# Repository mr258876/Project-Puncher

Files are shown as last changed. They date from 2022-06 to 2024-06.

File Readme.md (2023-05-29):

# Project Puncher
### 赛博音乐盒计划第二部分
### Cyber Musicbox Project Part II

## 项目文件结构 / Project File Structure
    |   Project Puncher
    |
    +---Models
    |       3D模型文件
    |       3D models of puncher
    +---Project_HolePuncher
    |       ESP32下位机程序
    |       Program for puncher controller based on ESP32
    +---Schematic
    |       项目电路图及PCB文件
    |       Circuit schematic & PCB
    \---Utilities
            上位机程序
            Host program runs on your PC

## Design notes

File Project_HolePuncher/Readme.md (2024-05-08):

# Project Puncher - 控制器程序 / Controller Program

## 硬件需求 / Hardware requirements
| 物品 / Item | 数量 / Amount |
|---|---|
| ESP32-S3-N16R8 | 1 |
| TMC2209 Stepper Driver | 3 |
| P028B123-10-IPS-CTP / P028X101-10-CTP 2.8' LCD with Touchscreen | 1 |
| PCF8574T | 1 |
| CH224K | 1 |

## 支持库 / Libraries Used
### 3rd party libraries:
- [lvgl/lvgl@^8.3.9](https://github.com/lvgl/lvgl)
- [teemuatlut/TMCStepper@^0.7.3](https://github.com/teemuatlut/TMCStepper)
- [robtillaart/PCF8574@^0.3.9](https://github.com/robtillaart/PCF8574)
### Modified & Distributed under MIT license:
- [owennewo/as5600_i2c_arduino](https://github.com/owennewo/as5600_i2c_arduino)
- [strange-v/FT6X36](https://github.com/strange-v/FT6X36)

## Compilation Note

### lv_i18n commands
Run `compile` in this folder to generate i18n files:
```bash
lv_i18n compile -t 'i18n/*.yml' -o 'src/ui/i18n'
```

### FATFS page code warning
In `.platformio/packages/framework-espidf/components/fatfs/src/ff.c`
Line 541
```patch
-541 static const BYTE Ct855[] = TBL_CT855;
+541 // static const BYTE Ct855[] = TBL_CT855;
```

### Arduino TinyUSB Header BUG
In `.platformio/packages/framework-arduinoespressif32/cores/esp32/USBCDC.cpp`

Line 18-19
```patch
-18 #include "USB.h"
-19 #if CONFIG_TINYUSB_CDC_ENABLED
+18 #include "USB.h"
+19 #if CONFIG_TINYUSB_CDC_ENABLED && CONFIG_TINYUSB_ENABLED
```

### stringop-truncation warning
In `.platformio/packages/framework-arduinoespressif32/cores/esp32/MacAddress.cpp`

Line 74-76
```patch
+74 #pragma GCC diagnostic push
+   #pragma GCC diagnostic ignored "-Wstringop-truncation"
 75 strncpy(cs, buf, sizeof(cs));  //strtok modifies the buffer: copy to working buffer.
+76 #pragma GCC diagnostic pop

+93 #pragma GCC diagnostic push
+   #pragma GCC diagnostic ignored "-Wstringop-truncation"
 94 strncpy(cs, buf, sizeof(cs));  //strtok modifies the buffer: copy to working buffer.
+95 #pragma GCC diagnostic pop
```

### printf format warning
In `.pio/libdeps/esp32s3/NimBLE-Arduino/src/nimble/nimble/host/src/ble_gap.c`
 
Line 318
```patch
-318 BLE_HS_LOG(INFO, "duration=%dms", duration_ms);
+318 BLE_HS_LOG(INFO, "duration=%ldms", duration_ms);
```

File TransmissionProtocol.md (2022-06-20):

# Transmission Protocol Over Serial
## Transmission Frame Discription
The transmission process is made up of frames. Each frame has 8 bytes, and is composed of three parts: Frame head, Frame body, and CRC byte.

### Frame Head
The frame head decides what type of data this frame contains. The definitnons of frame heads are listed in the folowing table.

| Frame Head | Description |
| --- | --- |
| 0xC0 | (H)Control Frame |
| 0xD0 | (H)Hole Data Frame |
| 0xE0 | (C)Client Response |
| 0xEF | (H/C)CRC Error |

*The letter before descrption means this message could only send by host or client.

### Frame body
The frame body takes 6 bytes after frame head. Content of frame body is various by frame head. 

"-----------" in following tables means the rest bytes are filled with 0x00.

#### Control Frame
Since there's no much controlling commands, only the first byte of frame body in control frame is effective, and all other bytes should be filled with 0x00. The definitions are as follow.

| Frame Body | Description |
| --- | --- |
| 0x01 -----------  | Query Client Status |
| 0x10 -----------  | Start Punch Mission |
| 0xA0 -----------  | Hole Data Transmission Begin  |
| 0xA1 -----------  | Hole Data Transmission End |

#### Hole Data Frame
Each hole data frame carries position data of one hole (related to pervious hole).

| X Position | Y position | Description |
| --- | --- | --- |
| 0xMM | 4 byte float ----  | Hole at X potision # MM, Z position equals the float. |

#### Client Response
Frame body in client response frames contains responses from the client. The first byte defines response type, and the rest 5 bytes are the message.

| Response Type | Message | Description |
| --- | --- | --- |
| 0x01 | ----------- | Client Response |
| 0x01 | 0x01 -----------  | Client Response: Success |
| ------------- | ----------------- | --------------------------------- |
| 0x10 | ----------- | Client Status |
| 0x10 | 0x01 -----------  | Client Status: Ready to transmit. |
| 0x10 | 0x0F -----------  | Client Status: Transmit disabled. |
| 0x10 | 0x10 -----------  | Client Status: Idle. |
| 0x10 | 0x11 -----------  | Client Status: Punching. |
| ------------- | ----------------- | --------------------------------- |
| 0xE0 | ----------- | Runtime Error |
| 0xE0 | 0x01 -----------  | Runtime Error: No hole data. |
| 0xE0 | 0xFF -----------  | Runtime Error: Unknown command |
| ------------- | ----------------- | --------------------------------- |
| 0xE1 | ----------- | Data Error |
| 0xE1 | 0x01 -----------  | Data Error: X out of range. |
| ------------- | ----------------- | --------------------------------- |
| 0xE2 | ----------- | Hardware Failure |
| 0xE2 | 0x01 0xMM ------  | Hardware Failure: Unable to read motor load values of motor #MM. (00 - X, 01 - Y) |
| 0xE2 | 0x02 -----------  | Hardware Failure: Unable to read magnet encoder values. |
| 0xE2 | 0x03 -----------  | Hardware Failure: Z axis got jammed. |

#### CRC Error Frame
CRC error frame means there's an error during transmission. No data would be contained in this frame.

### CRC Byte
CRC is a widely used verfying algorithm. CRC8 is used in this protocol, derived from the previous 7 bytes.

## Sending Movements to Client
### Step 1. Host
abc

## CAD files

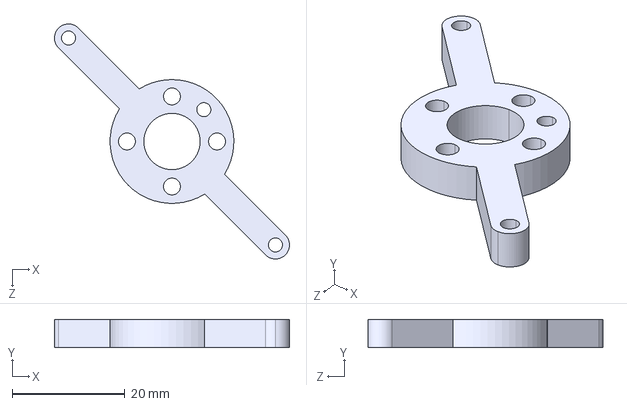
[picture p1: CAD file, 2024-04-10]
Models/冲头固定环.STEP
41.8 x 5.00 x 41.8 mm

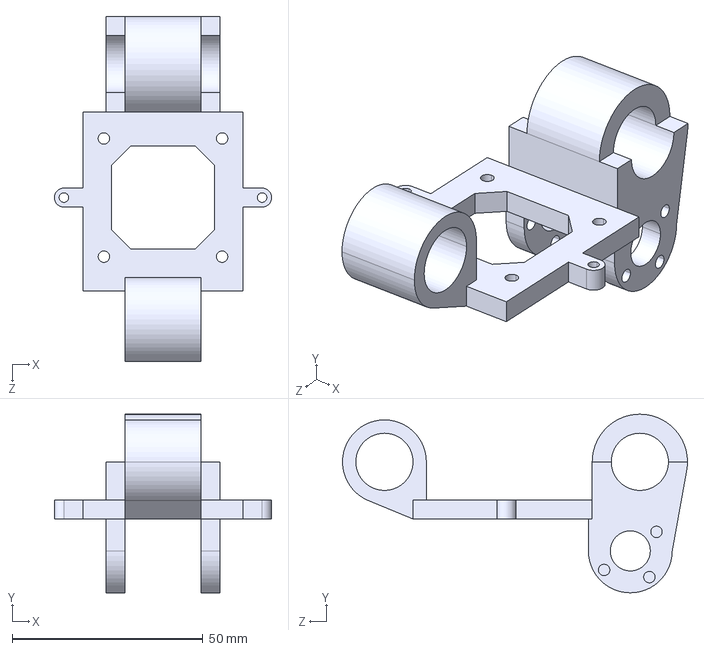
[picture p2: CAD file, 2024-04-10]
Models/打孔车.STEP
57.0 x 46.9 x 90.5 mm

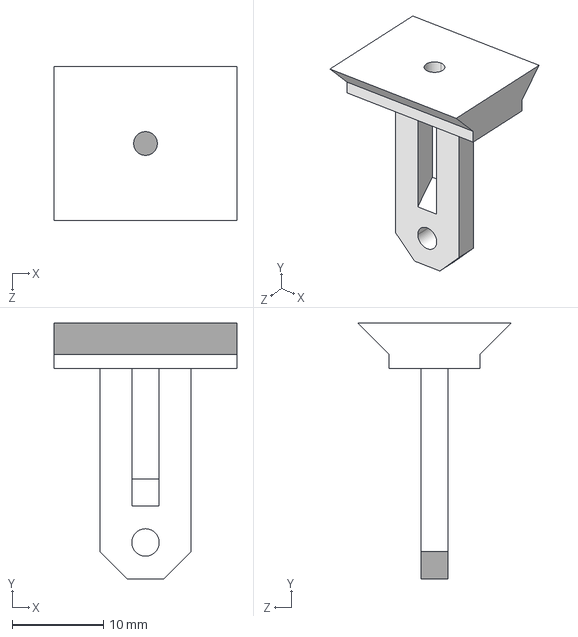
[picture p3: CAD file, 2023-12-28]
Models/打孔底座.STEP
20.0 x 28.0 x 16.8 mm

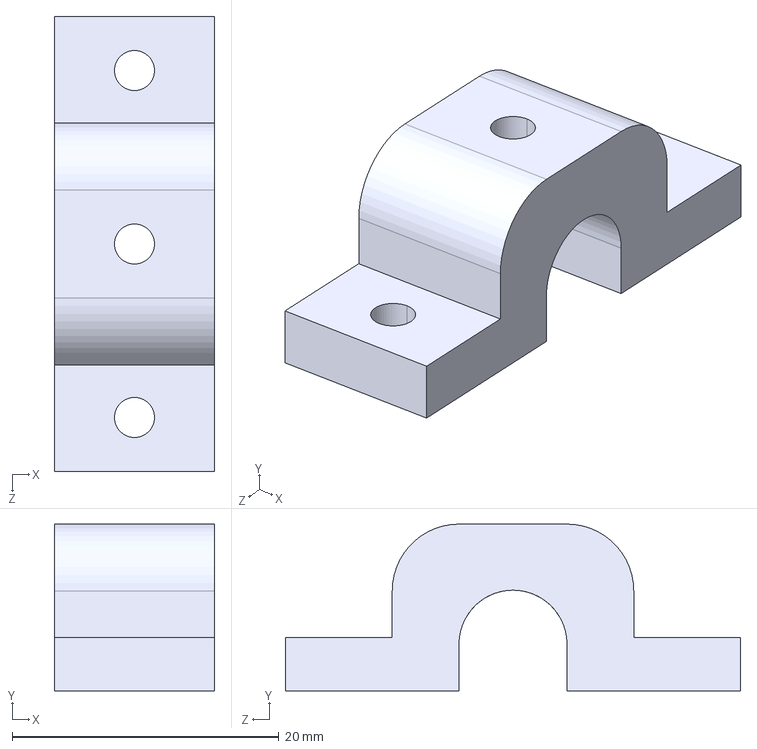
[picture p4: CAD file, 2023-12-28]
Models/滚轴盖.STEP
12.0 x 12.5 x 34.1 mm

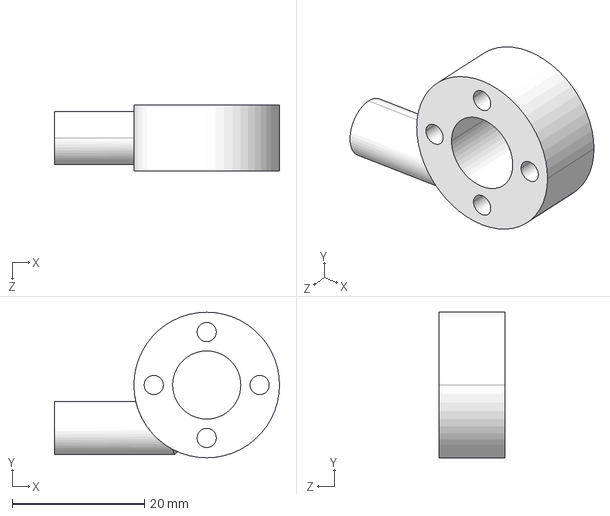
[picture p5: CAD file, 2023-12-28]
Models/打孔底座连接杆.STEP
34.0 x 22.0 x 10.0 mm

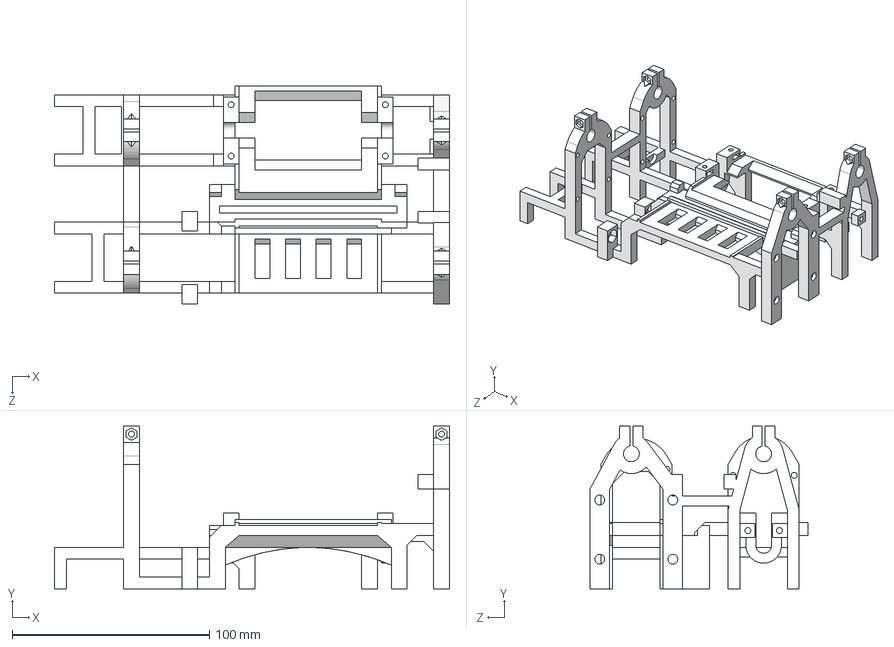
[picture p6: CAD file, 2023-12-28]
Models/底座.STEP
200.1 x 82.4 x 110.5 mm

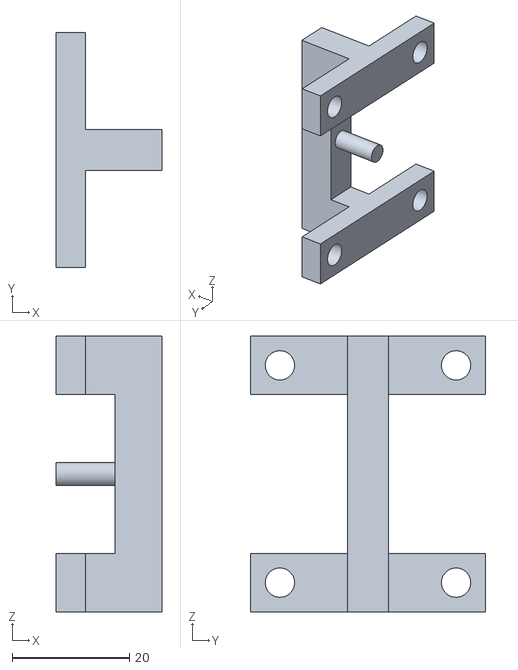
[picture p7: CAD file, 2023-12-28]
Models/同步齿轮支架.STL
18.0 x 40.0 x 47.0

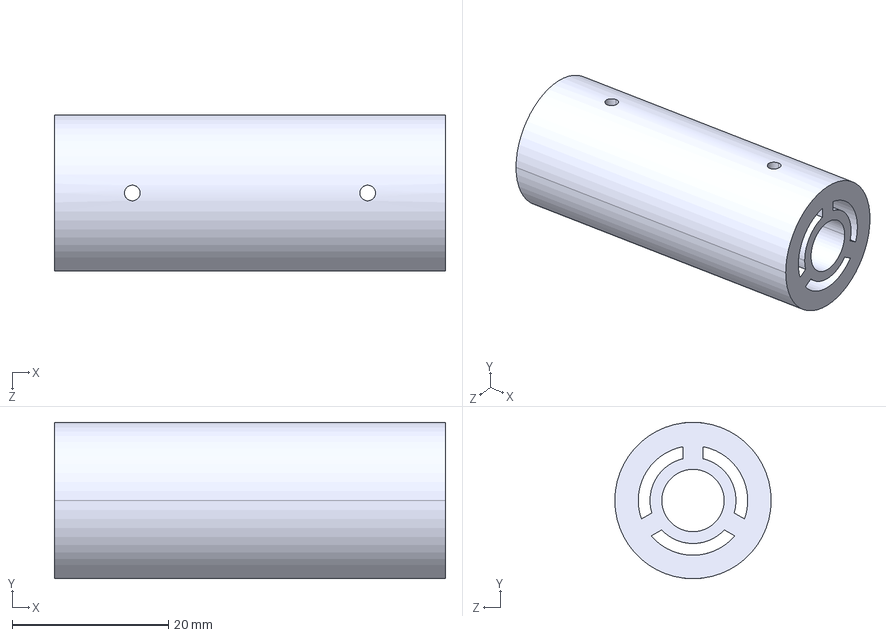
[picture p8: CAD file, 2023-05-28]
Models/滚轮轴.STEP
50.0 x 20.0 x 20.0 mm

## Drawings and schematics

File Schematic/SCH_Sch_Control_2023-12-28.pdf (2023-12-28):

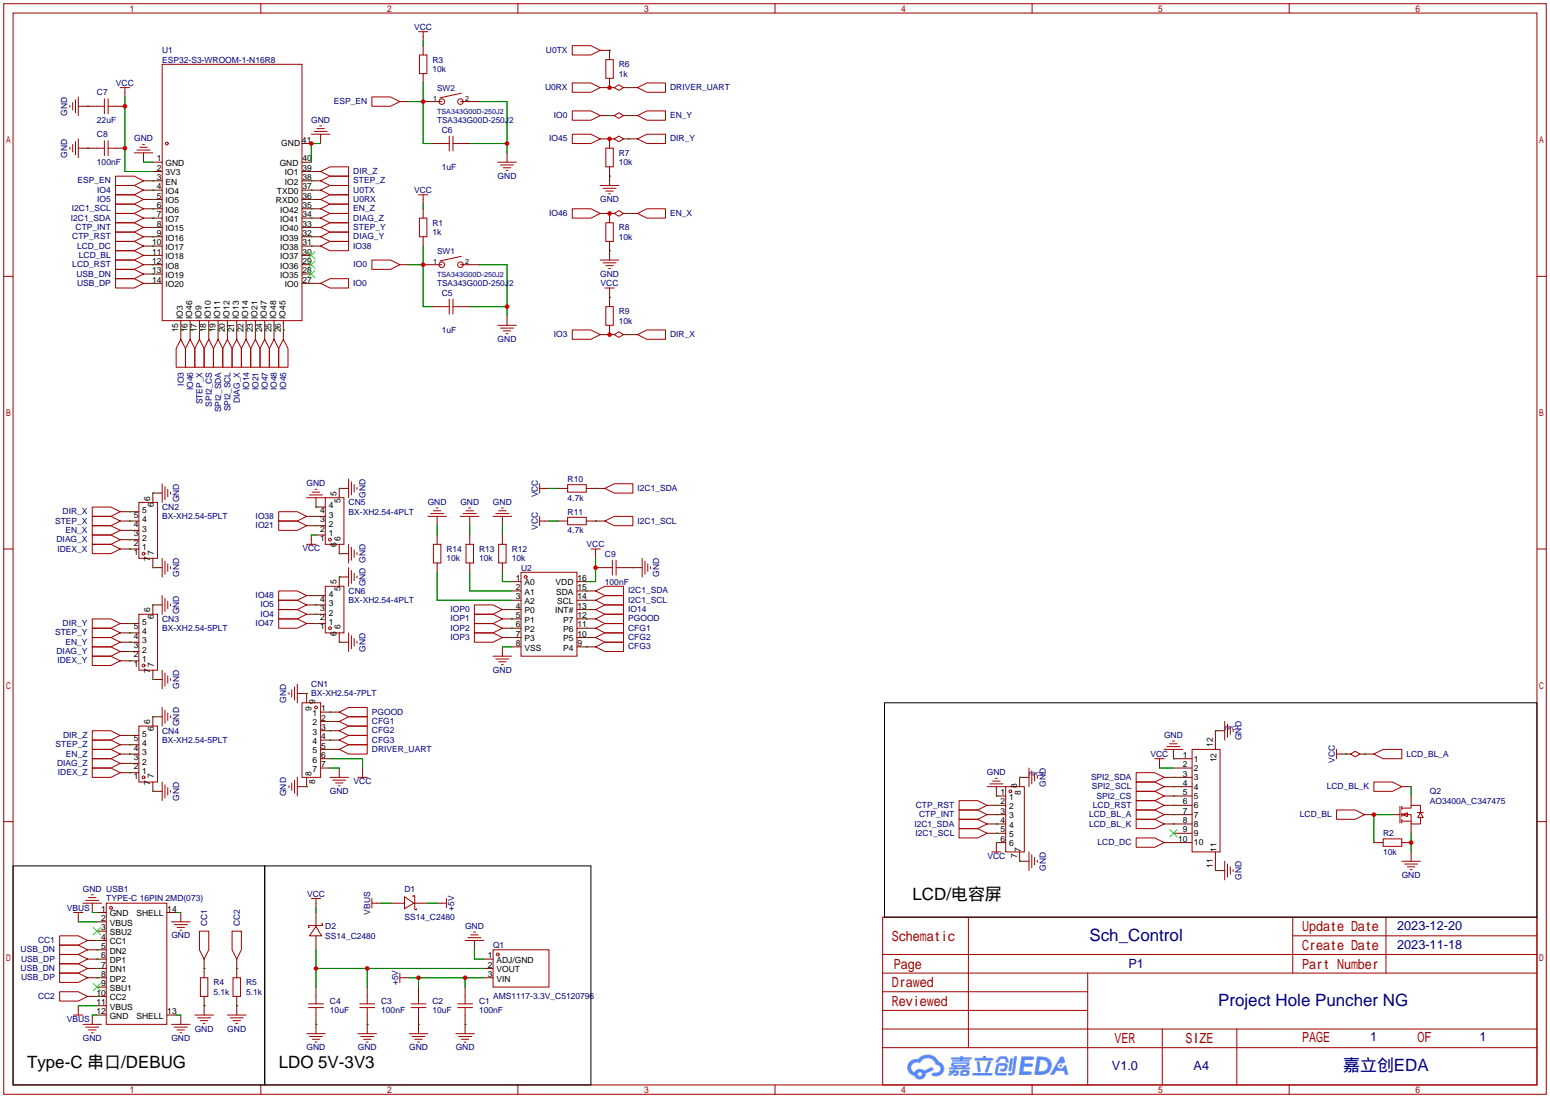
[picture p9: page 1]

Project Hole Puncher NG

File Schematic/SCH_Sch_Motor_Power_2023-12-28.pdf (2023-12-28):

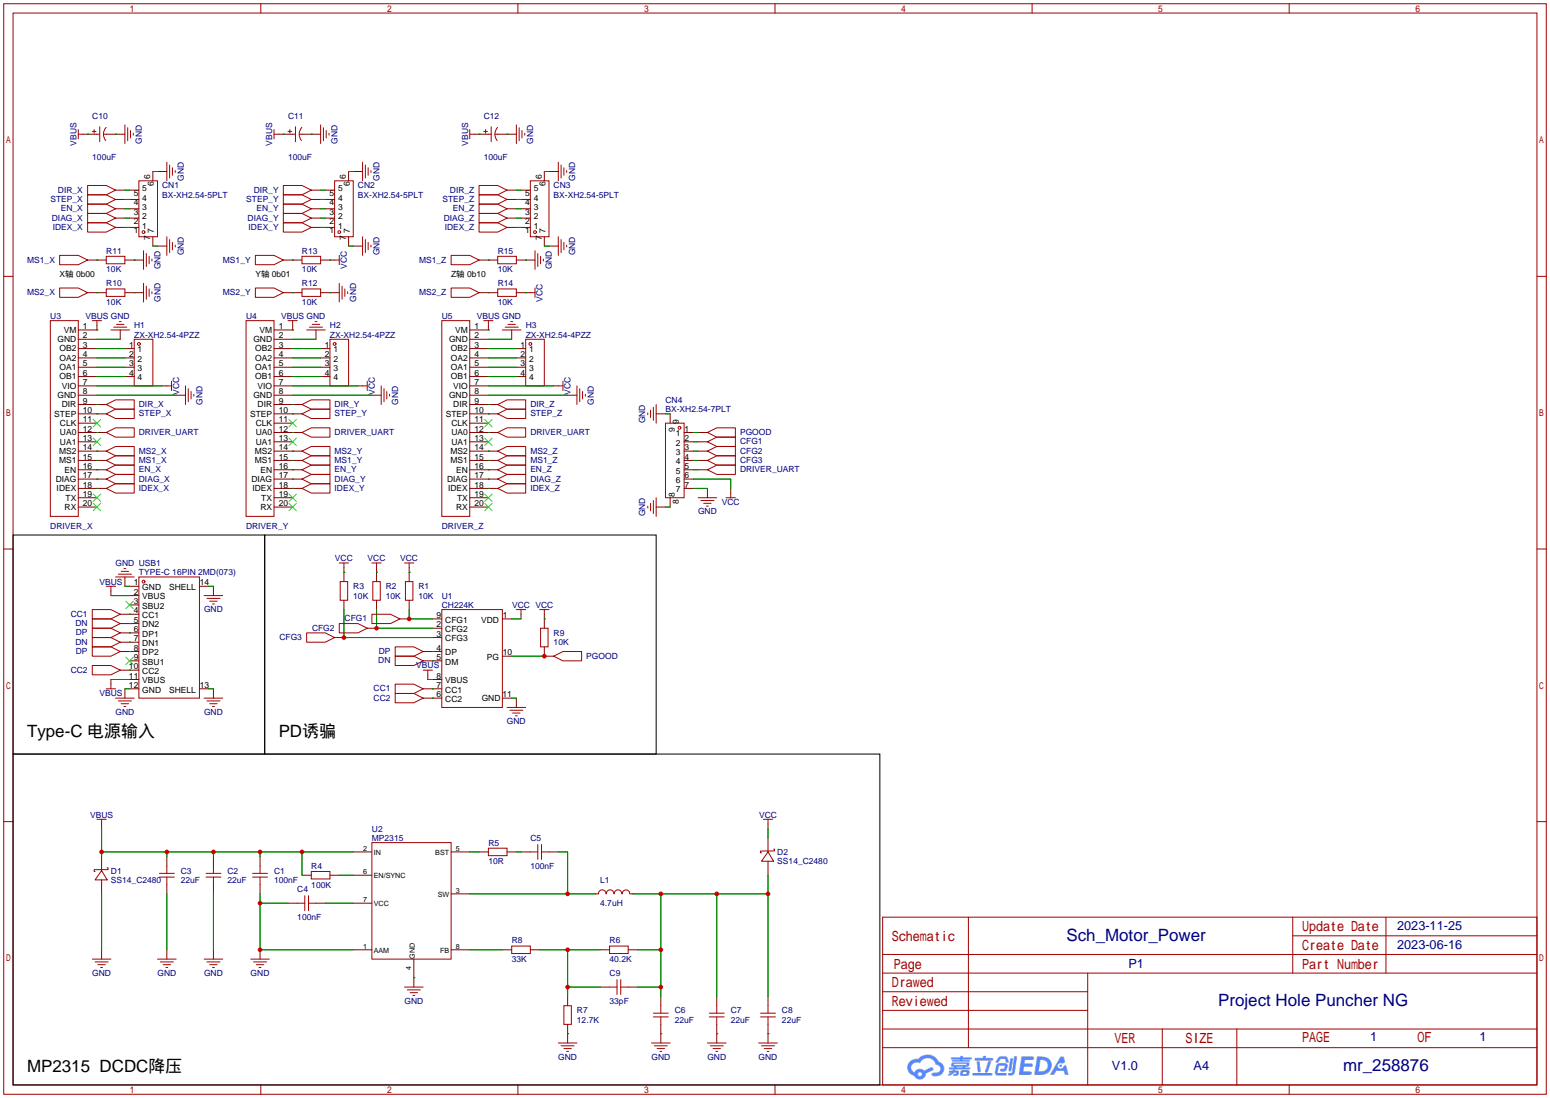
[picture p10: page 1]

Project Hole Puncher NG

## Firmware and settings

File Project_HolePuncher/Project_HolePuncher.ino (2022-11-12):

#include <BasicStepperDriver.h>
#include <Wire.h>
#include "AS5600.h"
#include <TMCStepper.h>

#include <WiFi.h>
#include <EEPROM.h>

#include "Project_HolePuncher_menu.h"
#include <PlatformDetermination.h>
#include <TaskManagerIO.h>

#include "PuncherScheduler.h"
#include "SerialCommand.h"

#include "lang_def.h"

//----------------------------------------电机控制用常量
#define MOTOR_STEPS 200
#define MICROSTEPS 8

#define DRIVER_SERIAL Serial2 // TMC controller Serial Port
#define R_SENSE 0.11f         // Match to your driver <- ???

//----------------------------------------任务
void initTcMenu(void *pvParameters);
void initMotor(void *pvParameters);
void runTcMenu(void *pvParameters);
void serialCommand(void *pvParameters);
void punchSchedule(void *pvParameters);
void runStepper(void *pvParameters);
void runEncoder(void *pvParameters);

//----------------------------------------任务句柄
TaskHandle_t runTcMenu_Handle;
TaskHandle_t serialCommand_Handle;
TaskHandle_t runEncoder_Handle;
TaskHandle_t wifiConnect_Handle;
TaskHandle_t wifiCommand_Handle;
TaskHandle_t punchSchedule_Handle;

//----------------------------------------资源锁
SemaphoreHandle_t I2CMutex = xSemaphoreCreateMutex();       // I2C互斥量
SemaphoreHandle_t SPIMutex = xSemaphoreCreateMutex();       // SPI互斥量
SemaphoreHandle_t Serial0Mutex = xSemaphoreCreateMutex();   // 串口0互斥量
SemaphoreHandle_t Serial2Mutex = xSemaphoreCreateMutex();   // 串口2互斥量
SemaphoreHandle_t XaxisBinary = xSemaphoreCreateBinary();   // X轴信号量(同步用)
SemaphoreHandle_t YaxisBinary = xSemaphoreCreateBinary();   // Y轴信号量(同步用)
SemaphoreHandle_t ZaxisBinary = xSemaphoreCreateBinary();   // Z轴信号量(同步用)
SemaphoreHandle_t PuncherBinary = xSemaphoreCreateBinary(); // 打孔机信号量(同步用)

//----------------------------------------磁编码器
AS5600 encoderZ;
int lastAngle = -1;
long rotatedAngle = 0;
bool encoderDisabled = true;

//----------------------------------------无线网络
#define WIFI_CONTROL_PORT 22576

int SSIDCount = 0;
WiFiServer server(WIFI_CONTROL_PORT);

//----------------------------------------电机控制变量
#define xenablePin 5 // x使能控制引脚
#define xdirPin 2    // x方向控制引脚
#define xstepPin 4   // x步进控制引脚
#define xdiagPin 33  // x方向过载引脚

#define yenablePin 23 // y使能控制引脚
#define ydirPin 18    // y方向控制引脚
#define ystepPin 19   // y步进控制引脚
#define ydiagPin 39   // y方向过载引脚

#define zenablePin 25 // z使能控制引脚
#define zdirPin 27    // z方向控制引脚
#define zstepPin 26   // z步进控制引脚
#define zdiagPin 36   // z方向过载引脚

bool Xenabled = false;
bool Yenabled = false;
bool Zenabled = false;
bool Ydown = false;
bool isPunching = false;

unsigned stepperX_to_wait;
unsigned stepperY_to_wait;
unsigned stepperZ_to_wait;

int xOptiCurr = 500; // 电机x工作电流
int xStbyCurr = 50;  // 电机x待机电流
int yOptiCurr = 500; // 电机y工作电流
int yStbyCurr = 50;  // 电机y待机电流
int zOptiCurr = 500; // 电机z工作电流
int zStbyCurr = 150; // 电机z待机电流

double xPerimeter = 0; // x轴转动周长
double yPerimeter = 0; // y轴转动周长
double zPerimeter = 0; // z轴转动周长

BasicStepperDriver stepperX(MOTOR_STEPS, xdirPin, xstepPin, xenablePin);
BasicStepperDriver stepperY(MOTOR_STEPS, ydirPin, ystepPin, yenablePin);
BasicStepperDriver stepperZ(MOTOR_STEPS, zdirPin, zstepPin, zenablePin);

TMC2209Stepper driverX(&DRIVER_SERIAL, R_SENSE, 0b00);
TMC2209Stepper driverY(&DRIVER_SERIAL, R_SENSE, 0b01);
TMC2209Stepper driverZ(&DRIVER_SERIAL, R_SENSE, 0b10);

long xPosition = 0;
long yPosition = 0;
long zLastMove = 0;

//-----------------------------------------tcMenu工具变量
char progressCA[9];

//-----------------------------------------
// 运行函数
// ----------------------------------------
void setup()
{
    Serial.begin(115200);
    Serial.println("Hole puncher booting...");

    // 为编码器启动I2C
    Wire.begin();
    Wire.setClock(400000);

    // 初始化tcMenu
    gfx.enableUTF8Print();    // 启用UTF-8以支持多语言
    gfx.setFontPosBaseline(); // 设置字体基线(虽然这里应该没啥用)
    setupMenu();
    installTheme();

    checkReset(); // 检查是否需要设置初始值

    menuProgress.setTextValue("idle"); // 将进度文字设为idle
    renderer.turnOffResetLogic();      // 关闭闲置回调函数
    // menuMgr.navigateToMenu(menuInfoView.getChild());

    // 初始化电机
    pinMode(xstepPin, OUTPUT);
    pinMode(xdirPin, OUTPUT);
    pinMode(ystepPin, OUTPUT);
    pinMode(ydirPin, OUTPUT);
    pinMode(zstepPin, OUTPUT);
    pinMode(zdirPin, OUTPUT);

    pinMode(xenablePin, OUTPUT);
    pinMode(yenablePin, OUTPUT);
    pinMode(zenablePin, OUTPUT);

    pinMode(xdiagPin, INPUT);
    pinMode(ydiagPin, INPUT);
    pinMode(zdiagPin, INPUT);

    digitalWrite(xenablePin, LOW); // 启用x方向电机
    digitalWrite(yenablePin, LOW); // 启用y方向电机
    digitalWrite(zenablePin, LOW); // 启用z方向电机

    getStepperPerimeters();

    stepperX.begin(menuRunningSpeedX.getAsFloatingPointValue() / xPerimeter * 60, MICROSTEPS);
    stepperX.setEnableActiveState(LOW);
    stepperY.begin(menuRunningSpeedY.getAsFloatingPointValue() / yPerimeter * 60, MICROSTEPS);
    stepperY.setEnableActiveState(LOW);
    stepperZ.begin(menuRunningSpeedZ.getAsFloatingPointValue() / zPerimeter * 60, MICROSTEPS);
    stepperZ.setEnableActiveState(LOW);
    stepperX.enable();
    stepperY.enable();
    stepperZ.enable();

    DRIVER_SERIAL.begin(115200);                                // 启动串口
    driverX.begin();                                            // x方向驱动板开始通讯
    driverX.microsteps(MICROSTEPS);                             // x方向驱动板设置微步大小
    driverX.rms_current(menuRunningCurrentX.getCurrentValue()); // x方向驱动板设置电流大小 (mA)
    driverY.begin();                                            // y方向驱动板开始通讯
    driverY.microsteps(MICROSTEPS);                             // y方向驱动板设置微步大小
    driverY.rms_current(menuRunningCurrentY.getCurrentValue()); // y方向驱动板设置电流大小 (mA)
    driverZ.begin();                                            // z方向驱动板开始通讯
    driverZ.microsteps(MICROSTEPS);                             // z方向驱动板设置微步大小
    driverZ.rms_current(menuRunningCurrentZ.getCurrentValue()); // z方向驱动板设置电流大小 (mA)

    // FreeRTOS创建任务
    //------------------------------创建tcMenu任务
    xTaskCreate(runTcMenu,          // 任务函数
                "runTcMenu",        // 任务名称
                8192,               // 任务堆栈大小
                NULL,               // 任务参数
                2,                  // 任务优先级
                &runTcMenu_Handle); // 任务句柄

    //------------------------------创建串口命令监听任务
    xTaskCreate(serialCommand,          // 任务函数
                "serialCommand",        // 任务名称
                8192,                   // 任务堆栈大小
                NULL,                   // 任务参数
                tskIDLE_PRIORITY,       // 任务优先级
                &serialCommand_Handle); // 任务句柄

    //------------------------------创建调度任务
    xTaskCreate(punchSchedule,          // 任务函数
                "punchSchedule",        // 任务名称
                8192,                   // 任务堆栈大小
                NULL,                   // 任务参数
                tskIDLE_PRIORITY,       // 任务优先级
                &punchSchedule_Handle); // 任务句柄

    xSemaphoreGive(XaxisBinary);   // 释放X轴同步信号量
    xSemaphoreGive(YaxisBinary);   // 释放Y轴同步信号量
    xSemaphoreGive(ZaxisBinary);   // 释放Z轴同步信号量
    xSemaphoreGive(PuncherBinary); // 释放打孔机同步信号量

    //--------------------连接Wifi--------------------
    menuSSID.setTextValue("N/A");
    menuIP.setIpAddress("127.0.0.1");
    if (menuWifi.getCurrentValue() == true)
    {
        asyncWifiConnect();
    }
    else
    {
        WiFi.mode(WIFI_OFF);
    }

    //--------------------检测编码器状态并启用编码器--------------------
    if (menuUseEncoderZ.getCurrentValue())
    {
        // openDialogNoButton(TEXT_ATTENTION, TEXT_CONNECTING_ENCODER, TEXT_EMPTY);
        Wire.beginTransmission(AS5600_I2C_ADDR);
        switch (Wire.endTransmission())
        {
        case 0:
            if (getMagnetStatus() == 1)
            {
                encoderDisabled = false;
                // Serial.println("Endocer detected and enabled.");
                //------------------------------创建磁编码器任务
                xTaskCreate(runEncoder,          // 任务函数
                            "runEncoder",        // 任务名称
                            4096,                // 任务堆栈大小
                            NULL,                // 任务参数
                            3,                   // 任务优先级
                            &runEncoder_Handle); // 任务句柄
            }
            else
            {
                // Serial.println("Magnet Error! Endocer Disabled!");
                // Serial.print("Error code: ");
                // Serial.println(getMagnetStatus());
                openDialog(TEXT_ERROR, TEXT_MAGNET_NOT_DETECTED, TEXT_ENCODER_NOW_DISABLED);
            }
            break;
        default:
            // Serial.println("Encoder Not Deceted and Disabled!");
            openDialog(TEXT_ERROR, TEXT_ENCODER_NOT_DECETED, TEXT_ENCODER_NOW_DISABLED);
            break;
        }
    }

    //--------------------X/Y轴归零--------------------
    // Y轴归零
    if (menuVirtualEndstopY.getBoolean())
    {
        // 中断
        // attachInterrupt(digitalPinToInterrupt(xdiagPin), onInterruptX, RISING);

        vTaskSuspend(punchSchedule_Handle); // 暂停调度任务

        uint8_t sgThrs = menuEndstopThresholdY.getCurrentValue();
        int sgReadings[] = {509, 509, 509, 509, 509, 509, 509, 509, 509, 509};
        int readingIndex = 0;
        int readingSum = 0;

        openDialogNoButton(TEXT_ATTENTION, TEXT_Y_AXIS, TEXT_ZEROING);

        driverY.rms_current(250);
        // driverY.SGTHRS(menuEndstopThresholdY.getCurrentValue());
        stepperY.startMove(-99999);
        stepperY.setRPM(20);
        while (stepperY.nextAction() > 0)
        {
            // Serial.println(driverY.SG_RESULT());
            // 10个读数取平均
            if (driverY.SG_RESULT() > 0)
            {
                sgReadings[readingIndex] = driverY.SG_RESULT();
                readingIndex++;
            }
            if (readingIndex > 9)
            {
                readingIndex = 0;
            }
            readingSum = 0;
            for (int i = 0; i < 10; i++)
            {
                readingSum += sgReadings[i];
            }

            if (readingSum / 10 > 0 && readingSum / 10 < sgThrs * 2) // SG_RESULT小于阈值两倍时代表电机过载，详见tmc209手册
            {
                stepperY.startMove(0);
                break;
            }
        }

        vTaskResume(punchSchedule_Handle); // 重启调度任务
        closeDialog();
    }


    // X轴归零
    if (menuVirtualEndstopX.getBoolean())
    {
        // 中断
        // attachInterrupt(digitalPinToInterrupt(xdiagPin), onInterruptX, RISING);

        vTaskSuspend(punchSchedule_Handle); // 暂停调度任务

        uint8_t sgThrs = menuEndstopThresholdX.getCurrentValue();
        int sgReadings[] = {509, 509, 509, 509, 509, 509, 509, 509, 509, 509};
        int readingIndex = 0;
        int readingSum = 0;

        openDialogNoButton(TEXT_ATTENTION, TEXT_X_AXIS, TEXT_ZEROING);

        driverX.rms_current(250);
        // driverX.SGTHRS(menuEndstopThresholdX.getCurrentValue());
        stepperX.startMove(-99999);
        stepperX.setRPM(20);
        while (stepperX.nextAction() > 0)
        {
            // Serial.println(driverX.SG_RESULT());
            // 10个读数取平均
            if (driverX.SG_RESULT() > 0)
            {
                sgReadings[readingIndex] = driverX.SG_RESULT();
                readingIndex++;
            }
            if (readingIndex > 9)
            {
                readingIndex = 0;
            }
            readingSum = 0;
            for (int i = 0; i < 10; i++)
            {
                readingSum += sgReadings[i];
            }

            if (readingSum / 10 > 0 && readingSum / 10 < sgThrs * 2) // SG_RESULT小于阈值两倍时代表电机过载，详见tmc209手册
            {
                stepperX.startMove(0);
                stepperX.setRPM(menuRunningSpeedX.getAsFloatingPointValue() / xPerimeter * 60);
                driverX.rms_current(menuRunningCurrentX.getCurrentValue());
                break;
            }
        }

        vTaskResume(punchSchedule_Handle); // 重启调度任务
        closeDialog();
    }

    // Y轴移动至准备位置
    if (menuVirtualEndstopY.getBoolean())
    {
        // 中断
        // attachInterrupt(digitalPinToInterrupt(xdiagPin), onInterruptX, RISING);

        vTaskSuspend(punchSchedule_Handle); // 暂停调度任务

        openDialogNoButton(TEXT_ATTENTION, TEXT_Y_AXIS, TEXT_ZEROING);

        stepperY.setRPM(menuRunningSpeedY.getAsFloatingPointValue() / yPerimeter * 60);
        driverY.rms_current(menuRunningCurrentY.getCurrentValue());
        moveYto(6);
        yPosition = 0;

        while (stepperY.nextAction() > 0)
        {
        }

        vTaskResume(punchSchedule_Handle); // 重启调度任务
        closeDialog();
    }

    // Serial.println("Puncher booted.");

    // 启动完成后切换至主菜单
    // menuMgr.navigateToMenu(&menuProgress);
}

// 电机运行现由loop函数处理 DEV.20220718
void loop()
{
    stepperX_to_wait = stepperX.nextAction();
    stepperY_to_wait = stepperY.nextAction();
    stepperZ_to_wait = stepperZ.nextAction();
}

// TcMenu 主题设置
void installTheme()
{
    renderer.setTitleMode(BaseGraphicalRenderer::TITLE_FIRST_ROW);
    renderer.setUseSliderForAnalog(false);
    menuProgress.setTextValue("");
    menuETA.setTime(secToTime(0));
    menuDuration.setTime(secToTime(0));
}

// 默认值设置
void checkReset()
{
    if (!menuResetStatus.getCurrentValue())
    {
        menuLengthX.setCurrentValue(800);
        menuLengthY.setCurrentValue(800);
        menuLengthZ.getLargeNumber()->setFromFloat(20.0);

        menuLengthTypeX.setCurrentValue(0);
        menuLengthTypeY.setCurrentValue(0);
        menuLengthTypeZ.setCurrentValue(0);

        menuDiamRatio.getLargeNumber()->setFromFloat(0);

        menuRunningSpeedX.setCurrentValue(120);
        menuRunningSpeedY.setCurrentValue(80);
        menuRunningSpeedZ.setCurrentValue(400);

        menuRunningCurrentX.setCurrentValue(500);
        menuRunningCurrentY.setCurrentValue(800);
        menuRunningCurrentZ.setCurrentValue(500);

        menuVirtualEndstopX.setBoolean(false);
        menuVirtualEndstopY.setBoolean(false);

        menuEndstopThresholdX.setCurrentValue(15);
        menuEndstopThresholdY.setCurrentValue(5);

        menuUseEncoderZ.setBoolean(false);

        menuWifi.setBoolean(false);

        menuResetStatus.setBoolean(true);
        saveValues(0);
    }
}

// 计算周长
void getStepperPerimeters()
{
    xPerimeter = menuLengthX.getAsFloatingPointValue() * (menuLengthTypeX.getCurrentValue() == 0 ? 1 : 3.14159265358979);
    yPerimeter = menuLengthY.getAsFloatingPointValue() * (menuLengthTypeY.getCurrentValue() == 0 ? 1 : 3.14159265358979);
    zPerimeter = menuLengthZ.getLargeNumber()->getAsFloat() * (menuLengthTypeZ.getCurrentValue() == 0 ? 1 : 3.14159265358979);
}

//------------------------------TcMenu 主进程循环函数
void runTcMenu(void *pvParameters)
{
    while (1)
    {
        vTaskDelay(pdMS_TO_TICKS(10));
        if (xSemaphoreTake(I2CMutex, portMAX_DELAY) == pdTRUE)
        {
            taskManager.runLoop();
            xSemaphoreGive(I2CMutex);
        }

        if (punchStartTime > 0)
        {
            menuDuration.setTime(secToTime((int)(millis() - punchStartTime) / 1000));
            menuDuration.setChanged(true);
        }
    }
}

//------------------------------串口监听函数
void serialCommand(void *pvParameters)
{
    byte serBuf[16] = {};
    unsigned long lastConn = millis();
    while (1)
    {
        if (xSemaphoreTake(Serial0Mutex, portMAX_DELAY) == pdTRUE)
        {
            while (Serial.available() > 15)
            {
                Serial.readBytes(serBuf, 16);
                Serial.write(handleSerialCommand(serBuf, 16), 16);
                lastConn = millis();
            }

            if (isSerialCommandEnabled())
            {
                // 30秒发一个心跳包
                if (millis() - lastConn > 30000)
                {
                    Serial.write(HeartBeatPackage, 16);
                }
                // 5秒内无回应关闭通讯
                if (millis() - lastConn > 35000)
                {
                    disableSerialCommand();
                }
            }

            xSemaphoreGive(Serial0Mutex);
        }
        else
        {
            vTaskDelay(pdMS_TO_TICKS(50));
        }
    }
}

//-----------------------------------------
// 打孔调度函数
// ----------------------------------------
void punchSchedule(void *pvParameters)
{
    while (1)
    {
        //    Serial.println(encoderZ.getAngle());
        if (!isPunching && puncherStatus == 0x11 && holeList.size() > 0) // 当状态为正在打孔且打孔队列有孔时才进行调度
        {
            // 计算剩余时间
            // 注意：calcETA需要访问holeList, 因此必须放在holeList.shift()前，否则在list size == 1时将会产生null pointer exception
            (String(holeFinished + 1) + "/" + String(holeCount)).toCharArray(progressCA, 9);
            menuProgress.setTextValue(progressCA);
            menuETA.setTime(secToTime(calcETA(menuRunningSpeedX.getAsFloatingPointValue(), menuRunningSpeedY.getAsFloatingPointValue(), menuRunningSpeedZ.getAsFloatingPointValue())));
            menuETA.setChanged(true);

            isPunching = true;
            Hole h = holeList.shift(); // 获取一个孔
            moveXpos(h.x);             // 移动X轴
            moveZ(h.z - lengthZ);      // 移动Z轴

            lengthZ = h.z;
        }
        else if (!isPunching && puncherStatus == 0x11 && holeList.size() == 0)
        {
            lengthZ = 0;
            rotatedAngle = 0;
            puncherStatus = 0x10;

            menuProgress.setTextValue("idle");
            menuETA.setTime(secToTime(0));
            menuETA.setChanged(true);
            menuDuration.setTime(secToTime(0));
            punchStartTime = 0;
        }

        if (Xenabled)
        {
            vTaskDelay(pdMS_TO_TICKS(100));
            if (stepperX_to_wait <= 0)
            {
                Xenabled = false;
                startYaxis();
            }
        }

        if (Zenabled)
        {
            vTaskDelay(pdMS_TO_TICKS(100));
            if (stepperZ_to_wait <= 0)
            {
                Zenabled = false;
                startYaxis();
            }
        }

        if (Yenabled)
        {
            vTaskDelay(pdMS_TO_TICKS(100));
            if (stepperY_to_wait <= 0)
            {
                if (Ydown)
                {
                    moveYto(0); // 若Y轴已移动至下方则回到初始位置
                    Ydown = false;
                }
                else
                {
                    Yenabled = false;
                    isPunching = false;

                    holeFinished += 1;
                }
            }
        }
    }
}

//-----------------------------------------
// 电机控制函数
// ----------------------------------------
void startYaxis() // X,Z轴移动完成后控制Y轴向下移动打孔
{
    if (!Xenabled && !Zenabled)
    {
        vTaskDelay(pdMS_TO_TICKS(50));
        if (encoderDisabled || abs(rotatedAngle / (4096 * menuDiamRatio.getLargeNumber()->getAsFloat()) * MOTOR_STEPS * MICROSTEPS + zLastMove) < 1)
        {
            moveYto(5.5);
            Ydown = true;
            rotatedAngle = 0;
        }
        else
        {
            Zenabled = true;
            stepperZ.startMove((long)(zLastMove + rotatedAngle / (4096.0 * menuDiamRatio.getLargeNumber()->getAsFloat()) * MOTOR_STEPS * MICROSTEPS));
            // Serial.println(rotatedAngle / (4096 * menuDiamRatio.getLargeNumber()->getAsFloat()) * MOTOR_STEPS * MICROSTEPS + zLastMove);
        }
    }
}

void moveZ(double mm)
{
    Zenabled = true;
    //     driverZ.rms_current(zOptiCurr);
    long toMove = (long)(-mm / zPerimeter * MOTOR_STEPS * MICROSTEPS);
    zLastMove = toMove;
    stepperZ.startMove(toMove);
    //     driverZ.rms_current(zStbyCurr);
}

void moveXpos(int pos)
{
    if (pos == -1)
    {
        moveXto(0);
    }
    else
    {
        moveXto(2 * (pos - 29) - 3.9);
    }
}

void moveXto(double mm)
{
    Xenabled = true;
    //    driverX.rms_current(xOptiCurr);
    long steps = (long)(mm / xPerimeter * (MOTOR_STEPS * MICROSTEPS) + 0.5);
    long toMove = xPosition - steps;
    stepperX.startMove(toMove);
    //    driverX.rms_current(xStbyCurr);
    xPosition = steps;
}

void moveYto(double mm)
{
    Yenabled = true;
    //    driverY.rms_current(yOptiCurr);
    long steps = (long)(mm / yPerimeter * (MOTOR_STEPS * MICROSTEPS) + 0.5);
    long toMove = steps - yPosition;
    stepperY.startMove(toMove);
    //    driverY.rms_current(yStbyCurr);
    yPosition = steps;
}

//----------------------------------------
// 磁编码器
//----------------------------------------
// 获取磁铁状态
// 返回值: -1  未检测到磁铁
// 返回值: 0   磁铁磁力过弱（距离过远）
// 返回值: 1   状态正常
// 返回值: 2   磁铁磁力过强（距离过近）
uint8_t getMagnetStatus()
{
    if (encoderZ.getMagnitude() < 750)
    {
        return 255;
    }

    AS5600_Status s = encoderZ.getStatus();
    if (s.magnetHigh)
    {
        return 2;
    }
    else if (s.magnetLow)
    {
        return 0;
    }
    return 1;
}

// 编码器运行函数
void runEncoder(void *pvParameters)
{
    while (1)
    {
        while (xSemaphoreTake(I2CMutex, portMAX_DELAY) != pdTRUE)
        {
            vTaskDelay(pdMS_TO_TICKS(10));
        }

        int v = encoderZ.getAngle();
        // v += encoderZ.getAngle();
        // v += encoderZ.getAngle();
        // v = v / 3;
        if (lastAngle != -1)
        {
            if (abs(v - lastAngle) > 2048)
            {
                rotatedAngle += v > 2048 ? v + lastAngle - 4096 : v - lastAngle + 4096;
            }
            else
            {
                rotatedAngle += v - lastAngle;
            }
        }
        else
        {
            rotatedAngle = 0;
        }

        lastAngle = v;
        xSemaphoreGive(I2CMutex);

        vTaskDelay(pdMS_TO_TICKS(25));
    }
}
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

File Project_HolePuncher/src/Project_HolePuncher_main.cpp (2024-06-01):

#include <Arduino.h>
#include "PuncherConf.h"
#include "PuncherSemaphore.h"

#include <lvgl.h>

#include "PuncherScheduler.h"
#include "PuncherMotors.h"

#include "MotorController/TMC_LEDCMotorController.h"
#include "PositionSensor/AS5600PositionSensor.h"
#include "ui/LVGL_PuncherUI.h"
#include "SerialInterface/SerialInterface.h"
#include "BLEInterface/BLEInterface.h"
#include "esp_vfs_fat.h"

static PuncherScheduler *scheduler;
static PowerManager *pm;
static wl_handle_t wl_handle_flash = WL_INVALID_HANDLE;

// ---------- Function declarations
void init_spiram();
void pm_init();
void motor_init();
void encoder_init();
void lvgl_init();
void serial_init();
void ble_init();
void fatfs_init();

void setup()
{
    ESP_LOGI("Puncher_Main", "Initializing...");

    scheduler = new PuncherScheduler();

    pm_init(); // Init power manager first or voltage acquire will fail

    scheduler->beginNVS();

    // serial_init();

    motor_init();

    encoder_init();

    ble_init();

    fatfs_init(); // must before lvgl_init

    lvgl_init();

    scheduler->begin();

    ESP_LOGI("Puncher_Main", "System booted.");
}

void pm_init()
{
    ESP_LOGI("Puncher_Main", "Power initializing...");

    pm = new PowerManager(CTP_I2C_SCL, CTP_I2C_SDA, PCF8574_INT);
    pm->begin();

    scheduler->attachPower(pm);

    ESP_LOGI("Puncher_Main", "Power initialized!");
}

void motor_init()
{
    ESP_LOGI("Puncher_Main", "Motor initializing...");

    DRIVER_SERIAL.begin(DRIVER_UART_BANDRATE);

    controller_X = new TMC_LEDCMotorController(MOTOR_STEPS, MICROSTEPS_X, xdirPin, xstepPin, xenablePin, xdiagPin, X_CONTROL_CHANNEL, &DRIVER_SERIAL, R_SENSE, 0b00);
    controller_Y = new TMC_LEDCMotorController(MOTOR_STEPS, MICROSTEPS_Y, ydirPin, ystepPin, yenablePin, ydiagPin, Y_CONTROL_CHANNEL, &DRIVER_SERIAL, R_SENSE, 0b01);
    controller_Z = new TMC_LEDCMotorController(MOTOR_STEPS, MICROSTEPS_Z, zdirPin, zstepPin, zenablePin, zdiagPin, Z_CONTROL_CHANNEL, &DRIVER_SERIAL, R_SENSE, 0b10);

    controller_X->begin(); // begin before attach
    controller_Y->begin();
    controller_Z->begin();

    controller_X->setActiveState(LOW);
    controller_Y->setActiveState(LOW);
    controller_Z->setActiveState(LOW);

    scheduler->attachMotors(controller_X, controller_Y, controller_Z);

    ESP_LOGI("Puncher_Main", "Motor initialized!");
}

void lvgl_init()
{
    ESP_LOGI("Puncher_Main", "Starting LVGL...");

    lvgl_ui->setLanguage(scheduler->getDisplayLanguage());
    lvgl_ui->begin(); // begin before attach

    ESP_LOGI("Puncher_Main", "LVGL initialized!");

    ESP_LOGI("Puncher_Main", "Configuring LVGL UI");

    scheduler->attachUI(lvgl_ui);

    ESP_LOGI("Puncher_Main", "LVGL UI ready!");
}

void serial_init()
{
    ESP_LOGI("Puncher_Main", "Starting USB Serial Interface...");

    usbInterface->begin();
    // usbInterface->enableLog();

    scheduler->attachUI(usbInterface);

    ESP_LOGI("Puncher_Main", "USB Serial Interface initialized!");
}

void ble_init()
{
    ESP_LOGI("Puncher_Main", "Starting BLE Interface...");

    bleInterface->begin();

    scheduler->attachUI(bleInterface);

    ESP_LOGI("Puncher_Main", "BLE Interface initialized!");
}

void encoder_init()
{
    ESP_LOGI("Puncher_Main", "Encoder initializing...");

    switch (scheduler->getZencoderType())
    {
    case 0:
        Wire.begin(I2C0_SDA, I2C0_SCL, 400000U);

        sensor_Z = new AS5600PositionSensor(&Wire, &I2C0Mutex);

        scheduler->attachPositionSensors(NULL, NULL, sensor_Z);
        break;

    default:
        break;
    }

    ESP_LOGI("Puncher_Main", "Encoder initialized!");
}

void fatfs_init()
{
    ESP_LOGI("Puncher_Main", "Mounting flash...");

    const esp_vfs_fat_mount_config_t mount_cfg = {
        .format_if_mount_failed = false,
        .max_files = 4,
        .allocation_unit_size = CONFIG_WL_SECTOR_SIZE,
    };

    ESP_ERROR_CHECK(esp_vfs_fat_spiflash_mount(FLASH_MOUNT_POINT, "fatfs", &mount_cfg, &wl_handle_flash));

    ESP_LOGI("Puncher_Main", "Flash mounted!");
}

void loop()
{
    vTaskDelete(NULL);
}

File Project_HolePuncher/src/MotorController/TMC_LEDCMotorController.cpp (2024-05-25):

#include "MotorController/TMC_LEDCMotorController.h"
#include "PuncherConf.h"
#include <hal/gpio_hal.h>

static TaskHandle_t evt_loop_handler = NULL;
static QueueHandle_t evt_queue = NULL;

typedef enum
{
    MC_EVT_NONE = 0,
    MC_EVT_ZEROING_DONE,
} TMC_LEDCMotorController_evt_t;

struct TMC_LEDCMotorController_evt_msg
{
    TMC_LEDCMotorController *controller;
    TMC_LEDCMotorController_evt_t msg;
};

void evt_loop(void *param)
{
    QueueHandle_t queue = *(QueueHandle_t *)param;
    TMC_LEDCMotorController_evt_msg msg;

    while (1)
    {
        xQueueReceive(queue, &msg, portMAX_DELAY);
        switch (msg.msg)
        {
        case MC_EVT_ZEROING_DONE:
            xSemaphoreTake(*DUARTMutex, portMAX_DELAY);
            {
                msg.controller->driver->TCOOLTHRS(0);
            }
            xSemaphoreGive(*DUARTMutex);

            if (msg.controller->zeroing_finish_callback)
            {
                msg.controller->zeroing_finish_callback();
            }
            break;

        default:
            break;
        }
    }

    vTaskDelete(NULL);
}

void IRAM_ATTR driver_diag_intr_handler(void *arg)
{
    TMC_LEDCMotorController *controller = (TMC_LEDCMotorController *)arg;

    if (controller->is_zeroing)
    {
        controller->stepper->__stop_from_int();
        TMC_LEDCMotorController_evt_msg msg = {controller, MC_EVT_ZEROING_DONE};
        BaseType_t xHigherPriorityTaskWoken = pdFALSE;
        controller->is_zeroing = false;
        xQueueSendFromISR(evt_queue, &msg, &xHigherPriorityTaskWoken);
    }
}

TMC_LEDCMotorController::TMC_LEDCMotorController(int motor_steps, int micro_steps, int dir_pin, int step_pin, int enable_pin, int int_pin, int ledc_pcnt_channel, HardwareSerial *SerialPort, float RS, uint8_t addr)
{
    stepper = new LEDCStepperDriver(motor_steps, dir_pin, step_pin, enable_pin, ledc_pcnt_channel);
    driver = new TMC2209Stepper(SerialPort, RS, addr);

    this->dir_pin = dir_pin;
    this->step_pin = step_pin;
    this->enable_pin = enable_pin;
    this->int_pin = int_pin;
    this->motor_steps = motor_steps;
    this->micro_steps = micro_steps;
}

TMC_LEDCMotorController::~TMC_LEDCMotorController()
{
}

motor_res_t TMC_LEDCMotorController::begin()
{
    /* Create queue and evt loop to process events */
    if (!evt_loop_handler)
    {
        evt_queue = xQueueCreate(8, sizeof(TMC_LEDCMotorController_evt_msg));
        xTaskCreate(evt_loop, "TLMCevtLoop", 4096, &evt_queue, 1, &evt_loop_handler);
    }

    /*  Notice:
        init process must follows:
            stepper init -> ISR init -> UART driver init
        or LEDC in stepper will not work.
        Nobody knows why :(
     */

    stepper->begin(60, micro_steps);
    stepper->setEnableActiveState(LOW);

    if (int_pin != 255)
    {
        pinMode(int_pin, INPUT_PULLDOWN);
        attachInterruptArg(digitalPinToInterrupt(int_pin), driver_diag_intr_handler, this, RISING);
    }

    xSemaphoreTake(*DUARTMutex, portMAX_DELAY);
    {
        driver->begin();
        driver->microsteps(micro_steps);
        driver->TCOOLTHRS(0);
        driver->dedge(0);   // Make sure we only step on rising edge
    }
    xSemaphoreGive(*DUARTMutex);

    return MOTOR_RES_SUCCESS;
}

motor_res_t TMC_LEDCMotorController::move(int32_t steps)
{
    stepper->startMove(reverse ? -steps : steps);
    return MOTOR_RES_SUCCESS;
}

motor_res_t TMC_LEDCMotorController::rotate_infinite(int dir)
{
    stepper->rotate_infinite(reverse ? -dir : dir);
    return MOTOR_RES_SUCCESS;
}

int32_t TMC_LEDCMotorController::stop()
{
    return stepper->stop();
}

int32_t TMC_LEDCMotorController::getPosition()
{
    return stepper->getPosition();
}

motor_status_t TMC_LEDCMotorController::getStatus()
{
    return stepper->isRunning() ? MOTOR_RUNNING : MOTOR_IDLE;
}

motor_res_t TMC_LEDCMotorController::setActiveState(uint8_t activeState)
{
    stepper->setEnableActiveState(activeState);
    return MOTOR_RES_SUCCESS;
}

motor_res_t TMC_LEDCMotorController::setReverse(bool reverse)
{
    this->reverse = reverse;
    return MOTOR_RES_SUCCESS;
}

motor_res_t TMC_LEDCMotorController::sleep(bool sleep)
{
    if (sleep)
        stepper->disable();
    else
        stepper->enable();
    return MOTOR_RES_SUCCESS;
}

int32_t TMC_LEDCMotorController::getStepsRemaining()
{
    return stepper->getStepsRemaining();
}

int32_t TMC_LEDCMotorController::getDirection()
{
    int dir = stepper->getDirection();
    return reverse ? -dir : dir;
}

motor_res_t TMC_LEDCMotorController::setSpeed(uint32_t stepsPerSec)
{
    stepper->setPulseFreq(stepsPerSec);
    return MOTOR_RES_SUCCESS;
}

motor_res_t TMC_LEDCMotorController::setCurrent(uint32_t rms_current)
{
    xSemaphoreTake(*DUARTMutex, portMAX_DELAY);
    {
        driver->rms_current(rms_current);
    }
    xSemaphoreGive(*DUARTMutex);
    return MOTOR_RES_SUCCESS;
}

motor_res_t TMC_LEDCMotorController::setMicroSteps(uint32_t microSteps)
{
    xSemaphoreTake(*DUARTMutex, portMAX_DELAY);
    {
        driver->mstep_reg_select(1);
        // The function in TMCStepper is not working, wtf
        switch (microSteps)
        {
        case 256:
            driver->mres(0);
            break;
        case 128:
            driver->mres(1);
            break;
        case 64:
            driver->mres(2);
            break;
        case 32:
            driver->mres(3);
            break;
        case 16:
            driver->mres(4);
            break;
        case 8:
            driver->mres(5);
            break;
        case 4:
            driver->mres(6);
            break;
        case 2:
            driver->mres(7);
            break;
        case 0:
            driver->mres(8);
            break;
        default:
            break;
        }
    }
    xSemaphoreGive(*DUARTMutex);
    return MOTOR_RES_SUCCESS;
}

motor_res_t TMC_LEDCMotorController::pingDriver()
{
    uint8_t __state = digitalRead(enable_pin);

    digitalWrite(enable_pin, HIGH);
    uint32_t en_state = 0;
    xSemaphoreTake(*DUARTMutex, portMAX_DELAY);
    {
        en_state = driver->enn();
    }
    xSemaphoreGive(*DUARTMutex);

    digitalWrite(enable_pin, __state); // write the original state back

    return en_state ? MOTOR_RES_SUCCESS : MOTOR_RES_FAIL;
}

motor_res_t TMC_LEDCMotorController::pingMotor()
{
    // running_current = rms_current;
    return MOTOR_RES_SUCCESS;
}
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

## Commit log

2022-07-01 Motor settings added.
2022-07-18 Calibrate messages added.
2022-07-18 calibration partially works
2022-07-20 a slight bug fix.
    [Project_HolePuncher.ino]
2022-07-20 bugfix: sending heartbeat packet all time
    [Project_HolePuncher.ino]
2022-07-26 Vitrual endstops now working
2022-07-26 Virtual endstops finally working
2022-07-27 Improved precision in Z axis.
2022-08-04 wifi switch now works
2022-08-23 Project Pause
    [冲头固定环.STEP, 底座.STEP, 打孔车.STEP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]
2023-05-28 版本7：更换进纸轴材质。X轴定位点更换至右侧。步进电机脉冲现由LEDC提供。
    [partitions.csv, 底座.STEP, 打孔车.STEP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]
2023-08-02 encoder implementation
2023-08-03 encoder debounce fix
2023-11-29 project migrate to ESP32S3
    [partitions.csv]
2023-11-30 usb debug configuration / ctp port
    [partitions_for_recovery.csv]
2023-12-06 ctp fix / lvgl button test / driver UART fix
    [Project_HolePuncher_main.cpp, PuncherConf.h, lv_port.c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]
2023-12-09 setting menu test
    [partitions.csv]
2023-12-17 NVS value display fix
    [LVGL_PuncherUI.cpp, Project_HolePuncher_main.cpp, PuncherScheduler.cpp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]
2023-12-19 feed paper autostop fix
    [PuncherScheduler.cpp]
2023-12-19 feed paper speed fix
    [Project_HolePuncher_main.cpp, PuncherScheduler.cpp, PuncherScheduler.h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]
2023-12-21 dev archive 231221
    [同步齿轮支架.STL, 底座.STEP, 打孔底座.STL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]
2023-12-22 add arduino_tinyusb to component
2023-12-24 switched to idf native tinyusb cdc implementation
2023-12-28 X axis fix
2023-12-28 base 3d model update
    [打孔底座.STEP, 打孔底座.STL]
2023-12-29 i2c wire selection
2023-12-30 AS5600 magnet encoder
2024-01-05 z axis fix
2024-01-08 update ui status on attach
2024-01-14 magnet encoder switch
2024-01-15 framework update
2024-04-10 driver LEDC fix
2024-04-10 axis helper motor sleep fix
    [MotorController.h, Project_HolePuncher_main.cpp, PuncherScheduler.cpp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]
2024-04-10 model update
    [冲头固定环.STEP, 打孔车.STEP]
2024-04-11 power manager update & hw err notify
2024-04-13 Y axis helper fix
    [PuncherScheduler.cpp]
2024-04-25 as5600 calibration
2024-05-08 encoder cali fix
2024-05-11 encoder fix after calibration
    [PuncherScheduler.cpp]
2024-05-12 stepper driver auto resolution adjust
2024-05-15 temporary fix for ledc not working in high frequency
2024-05-15 lcd brightness switch to native ledc api
2024-05-24 ledc pwm fix
2024-05-25 stepper driver code cleanup
2024-05-25 final pwm output fix
    [TMC_LEDCMotorController.cpp]
2024-06-01 fix zeroing msg not closing
    [PuncherScheduler.cpp]
